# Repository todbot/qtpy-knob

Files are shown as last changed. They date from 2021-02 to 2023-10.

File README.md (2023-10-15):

# QTPy-Knob

QT Py USB Media Knob using rotary encoder &amp; neopixel ring

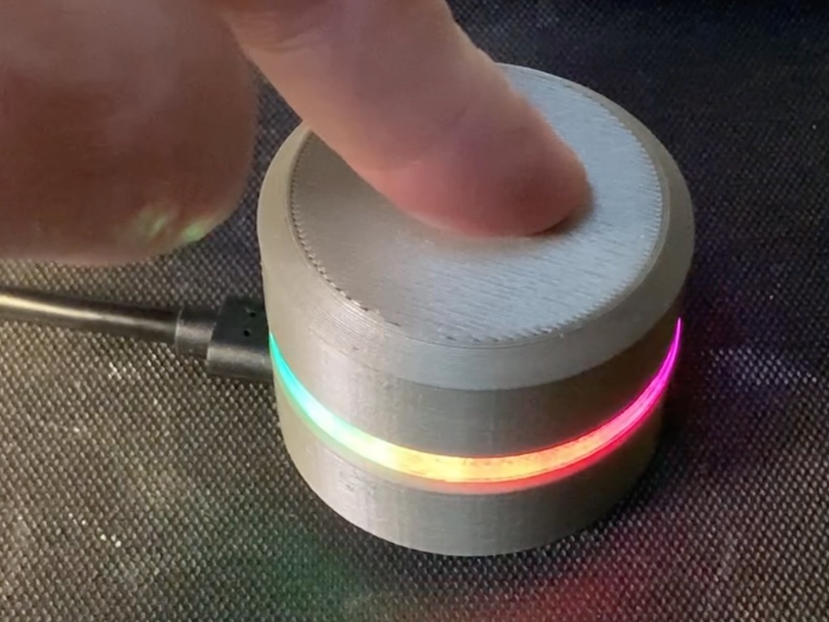
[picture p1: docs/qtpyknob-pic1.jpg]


The QTPy-Knob features:
- Media knob for volume up/down/mute with "qtpy-knob.py" CircuitPython program
- Stylish design reminiscent of Griffin Powermate
- Recessed USB-C connector to for safety
- No screws needed for assembly
- Only 3 wires needed to solder (none if you want to forgo LED lighting)
- Reprogrammable for any USB macro key action via CircuitPython

A small video about it: https://www.youtube.com/watch?v=pt7JgoSlgOg

This is an attempt to make a minimal and easy-to-build version of similar, previous projects like:
- https://learn.adafruit.com/trinket-usb-volume-knob
- https://learn.adafruit.com/media-dial

## Components

Parts needed:

- Adafruit QT Py (Originally for [QTPy M0](https://www.adafruit.com/product/4600) or [XIAO SAMD21](https://www.seeedstudio.com/Seeeduino-XIAO-Arduino-Microcontroller-SAMD21-Cortex-M0+-p-4426.html), but [QTPy RP2040](https://www.adafruit.com/product/4900) does work via a `fakerotaryio` hack)
- Adafruit Neopixel Ring (https://www.adafruit.com/product/1463 or equiv)
- Rotary encoder (PEC11-4120F-S0018 or equiv. The 3D printed case expects encoder w/ 20mm shaft & 7mm threaded barrel, see [here for mods if using a 15mm encoder](https://github.com/todbot/qtpy-knob/issues/2))
- 3D printed enclosure (see "cad" folder)

## Software

For some of the scripts and for some QT Py variants,
there are [prebuilt UF2 firmware images in Releases](https://github.com/todbot/qtpy-knob/releases).

Otherwise, software installation consists of:
- Install CircuitPython on the QT Py
- Install required CircuitPython libraries to QT Py
- Copy qtpy_knob.py to QT Py

The CircuitPython installation step is described here: https://learn.adafruit.com/welcome-to-circuitpython/installing-circuitpython

The last two steps can be accomplished with the below

```
git clone https://github.com/todbot/qtpy-knob
cd qtpy-knob
pip3 install circup
circup install -r requirements.txt
cp qtpy_knob.py /Volumes/CIRCUITPY/code.py
```

**RP2040 NOTE:** And if you have a QTPy RP2040, be sure to copy the "fakerotaryio.py" file to CIRCUITPY as well.

### Variations

There are a few variations of the code provided:
- [`qtpy_knob.py`](./qtpy_knob.py)  -- volume up / down and mute
- [`qtpy_knob_scroller.py`](./qtpy_knob_scroller.py) -- performs vertical & horizontal scrolling
- [`qtpy_knob_midi_cc.py`](./qtpy_knob_midi_cc.py) -- sends MIDI CC instead of keyboard/mouse
- [`qtpy_knob_simple.py`](./qtpy_knob_simple.py) -- no neopixel stuff, just encoder and USB vol up/down sending

## Assembly

Steps:

1. Plug rotary encoder to bottom of QT Py. If your encoder has metal on the bottom,
add a bit of tape (Kapton, Scotch, electrical) in between the QT Py and the encoder.  If your encoder has mounting tabs, cut them off.  Solder the five pins.

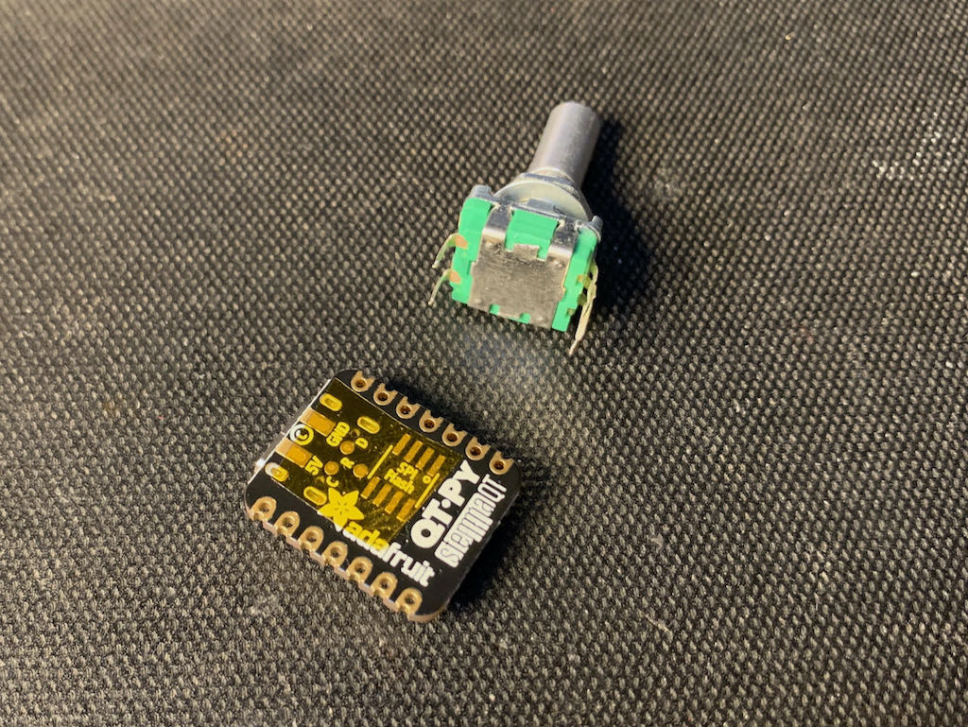
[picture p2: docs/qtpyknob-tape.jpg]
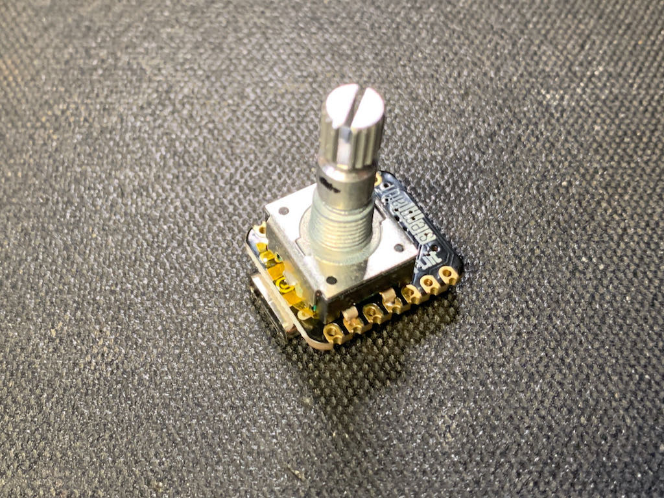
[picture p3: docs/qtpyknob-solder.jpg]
  

2. Print out the enclosure on your 3d printer. Standard 0.2mm at 20% infill is fine.  The STL files are:

- `qtpyknob-base.stl` -- Base that houses the QT Py & rotary encoder
- `qtpyknob-basecap.stl` -- Cap that goes on the bottom of the base
- `qtpyknob-knob.stl` -- Knob that you turn
- `qtpyknob-diffuser.stl` -- Light diffuser that goes between base & knob, should be printed with translucent or clear plastic. Or you can leave it out. Or you can approxiate it with a disk cut out clear plastic like a CD case

Use the rotary encoder's washer & screw to hold QTPy+encoder assembly

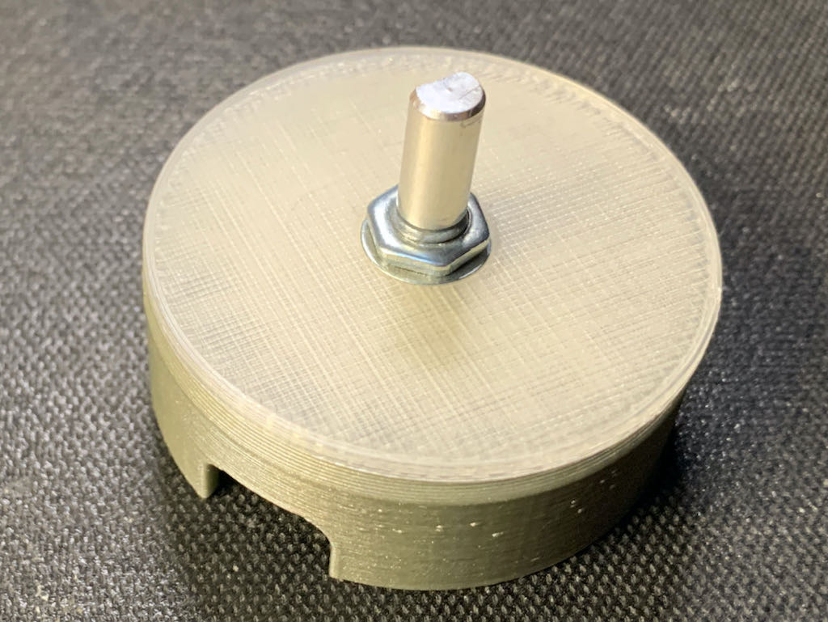
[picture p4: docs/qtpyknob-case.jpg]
  

3. Solder three wires to the Neopixel ring, insert the ring into the enclosure and solder the wires to the 3V, Gnd, and MI pins of the QT Py.  Use a bit of hot glue to secure the Neopixel ring if it doesn't snap in.

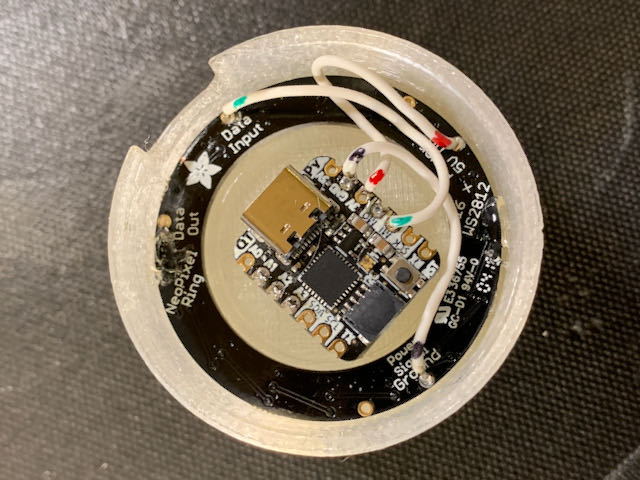
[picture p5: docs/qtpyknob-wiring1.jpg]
  

4. Snap the bottom cap on and the knob top on and you're done with physical assembly!

  

### Wiring diagram

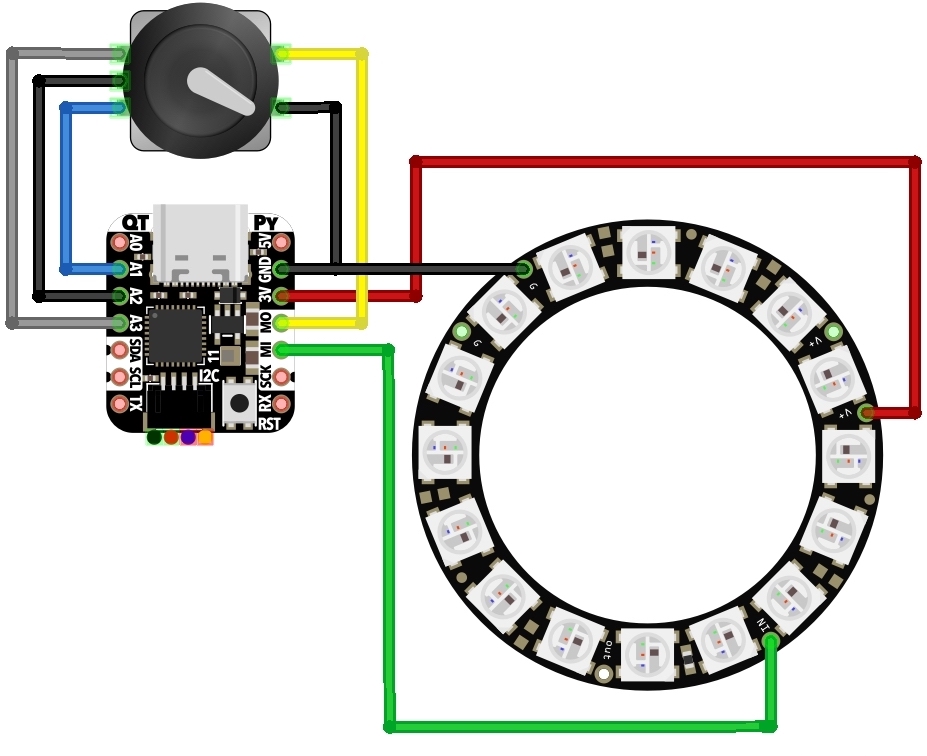
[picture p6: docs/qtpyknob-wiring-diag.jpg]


### Assembly animation



## Useful links

Resources that helped me out on this:

- https://learn.adafruit.com/media-dial
- https://learn.adafruit.com/make-it-a-keyboard/circuitpython
- https://github.com/adafruit/Adafruit_CircuitPython_HID/tree/master/examples
- https://circuitpython.readthedocs.io/projects/hid/en/latest/api.html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
- https://learn.adafruit.com/trinket-usb-volume-knob

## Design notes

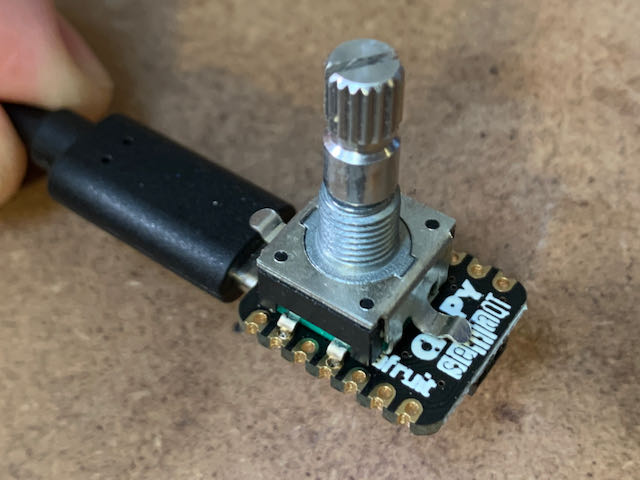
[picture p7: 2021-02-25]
docs/qtpyknob-encoder-mount.jpg

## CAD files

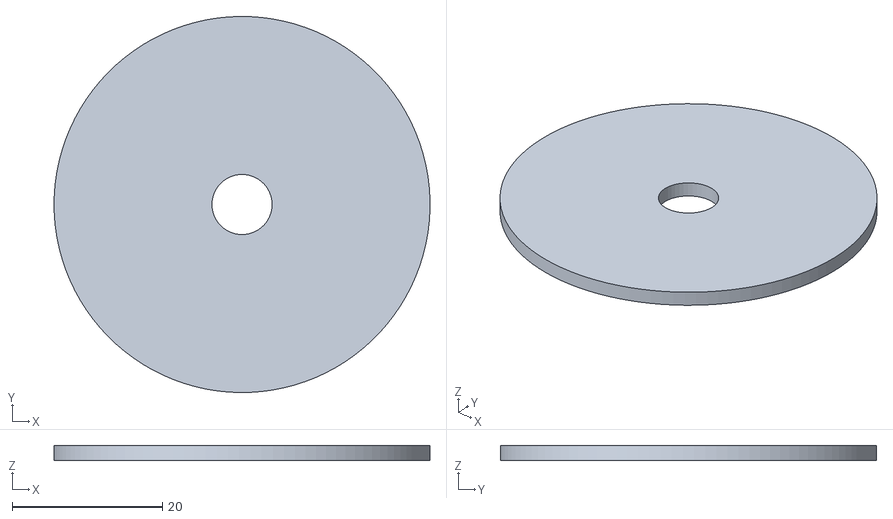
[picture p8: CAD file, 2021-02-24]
cad/qtpyknob-diffuser.stl
50.0 x 50.0 x 2.00

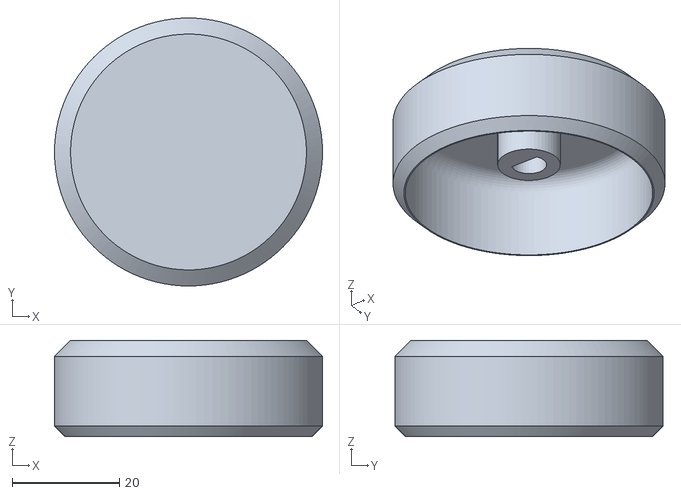
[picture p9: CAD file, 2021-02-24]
cad/qtpyknob-knob.stl
50.0 x 50.0 x 18.0

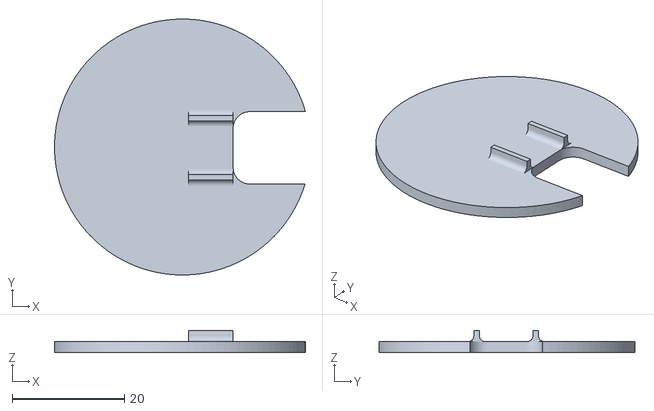
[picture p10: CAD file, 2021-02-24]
cad/qtpyknob-basecap.stl
44.8 x 45.7 x 4.00

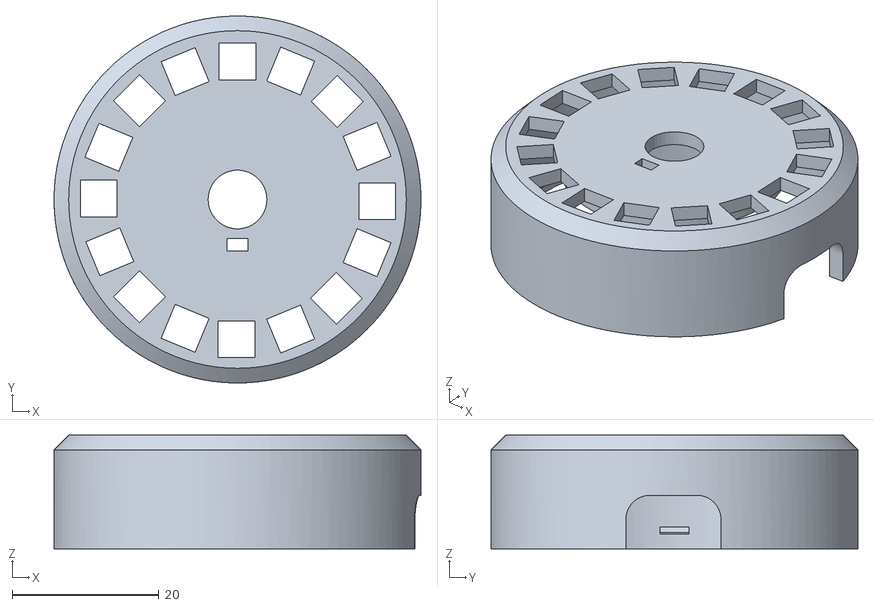
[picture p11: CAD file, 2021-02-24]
cad/qtpyknob-base.stl
50.0 x 50.0 x 15.5

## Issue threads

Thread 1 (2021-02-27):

Renaming to avoid "-" and use "_".

dglaude, 2021-02-27:
Thank you for this piece of code and great idea.

Just a suggestion to avoid "-" into python file name and user "_" instead.

This permit to never rename the original file from the project and have a code.py like this:
```
import qtpy_knob_simple
#import qtpy_knob_scroller
#import qtpy_knob
```

PS: I have both QT-Py and Seeduino XIAO in the same form factor... my QT-Py is more precious because it has reset button, Stemma-QT pin, RGB. So I wanted to rename the pin for XIAO use... but there is no need, your code works out of the box on the same physical pin with the same code. Only the through hole seems smaller on the XIAO so it does not fit perfectly flush. Did I mention it does also kind of work without soldering!!!

todbot, 2021-02-27:
Hi David! Thanks, but I wasn't intending any of these .py to be used straight but to be copied over as the `code.py`.  How can it work if you're importing them?  Wouldn't the `while True:` mess it up?

todbot, 2021-02-27:
Oh and yes we are fortunate that the CircuitPython config for the XIAO contains both the pin names it has on the bottom as well as the pin names of the QT Py in its 'board' object.  I was pleasantly surprised too! (because I have a pile of XIAOs and have been wanting to use them up, so in the video, both of the enclosed units are actually XIAO boards :-)

dglaude, 2021-02-27:
The import from code.py works fine.
That is what Info all the time, my code.py is just a program selector or choose the test I want to run.

To answer your question, you just never return from the import.

One may also want to import directly from REPL and have no code.py and no main.py.

I see no good reason to use character that block that.

dglaude, 2021-02-27:
The import from code.py works fine.
That is what Info all the time, my code.py is just a program selector or choose the test I want to run.

To answer your question, you just never return from the import.

One may also want to import directly from REPL and have no code.py and no main.py.

I see no good reason to use character that block that.

todbot, 2021-02-27:
Interesting!  Okay, sounds like a good change to make then.  Do you have a link to your program selector? Sounds pretty useful.

dglaude, 2021-02-27:
My program selector is to put a # in front of all but the code I want to test. :-)

But there was a menu system I once saw for board with a screen, there is a feature to select what will be the "code.py" or "main.py" at next boot. This is useful if you have multiple games on a PyGamer.

What I made is a magtag boot selector: https://gist.github.com/dglaude/4bf8d0a13c9c8ca8b05d6c0e9176bd20
Later that was turned into a guide with a GUI: https://learn.adafruit.com/adafruit-magtag-project-selector

Closed 2021-02-27.

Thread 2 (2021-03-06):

minor issues around encoder fit

scruss, 2021-03-06:
Noticed a couple of things when using the specified Bourns PEC11-4215F-S24 encoder:

1. The diffuser ring is too thick for the lock nut to fasten. It's 2 mm thick, and there's exactly 2 mm of thread left on the encoder.
2. The D-shaft cutout in the top is too deep to allow the encoder shaft switch to trigger.

Otherwise, it's a fantastic project and very easy to make. Yes, I used a Seeeduino XIAO, too

## Workarounds

I made the central part of the diffuser thinner so the lock nut would fasten. Excuse the OpenSCAD, it's all I know:

    bbox = [ 49.988811, 49.994404, 2.000000 ];
    minima = [ -25.000000, -24.997202, 2.700000 ];

    difference() {
        translate([-bbox.x/2, -bbox.y/2, 0])translate(-minima)import("qtpyknob-diffuser.stl");
        translate([0,0,0.8])cylinder(d=bbox.x/2, h=bbox.z);
    }

For the D-shaft cutout, a blob of Blu Tack of just the right size mostly fixes the issue.

todbot, 2021-03-06:
Doh! So many encoder options to pick from.
I see now that the ones I'm using are PEC11-4120F-S0018 equivalent (i.e. 20mm shaft with 7mm threaded barrel and you've got a 15mm shaft with a 5mm threaded barrel.  I think your option is more common. I have a bunch of extra encoders from some modular synth projects. :)

I'll add a note about expected encoder in the README and keep this issue open for others to easily see it.  Thanks!  I totally forgot to specify the encoder parameters.

bdgraham, 2022-08-09:
Obviously due to the negligence of the user (me) not reading the readme fully, the rotary encoder I have won't fit into the d-shaft cutout as the shaft I have is the regular kind.  Do you have a qtyknob-knob.stl available with the regular size shaft cut out?  All measurements are spot on otherwise.  If not, totally fine as I can extract that portion in blender if needed.  Awesome work, I've really wanted to make a functional volume knob for a while!  I also created an svg for the diffuser as I am going to be using a laser cutter for that part.  If you would like me add that file to your repo, please let me know!

For reference, this is the rotary encoder I am using - https://www.amazon.com/dp/B08728K3YB?psc=1&ref=ppx_yo2ov_dt_b_product_details

todbot, 2022-08-09:
Hi @bdgraham
I can provide solid models from the included Fusion360 file if that'd work better in Blender for you. But no, I've not made either a knurled-shaft or a slotted-shaft version of the knob cap.

And yeah if you have a diffuser SVG you'd like to share, submit a PR, I'd love to add it!

bdgraham, 2022-08-09:
@todbot A solid model would be great, thanks!  I'll get that PR submitted in the meantime.

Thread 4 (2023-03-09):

2023 - circuit python 8.0.3 - sequential pins rotaryio?

xgpt, 2023-03-09:
le.
main.py output:
Traceback (most recent call last):
  File "main.py", line 30, in <module>
RuntimeError: Pins must be sequential GPIO pins

Code done running.

Press any key to enter the REPL. Use CTRL-D to reload.

todbot, 2023-03-09:
Looks like you're using a QT Py RP2040.  This project was created before those existed, and only works with the original QT Py M0.

xgpt, 2023-03-11:
Oh interesting, I wasn't sure why that might be happening!

adalovebass, 2023-10-14:
Sorry to bump, but @xgpt , did you find a workaround? I may just cut my pins and bridge with wires to sequential pins... :/

And @todbot , would you be willing to update the "components" section to call out the M0? I didn't realize there were different versions of the QT Pi and I didn't order directly from the link. Thank you both!

todbot, 2023-10-14:
@adalovebass  Yep I'll do that.  I'll also see about a solution for the RP2040.

adalovebass, 2023-10-14:
That's awesome! Technically I'm on a xiao-rp2040, but all the .pins are in the same spot as the QT Pi, I just have less memory (and need to cherry-pick my python modules).

xgpt, 2023-10-14:
> Sorry to bump, but @xgpt , did you find a workaround? I may just cut my pins and bridge with wires to sequential pins... :/
>
> And @todbot , would you be willing to update the "components" section to call out the M0? I didn't realize there were different versions of the QT Pi and I didn't order directly from the link. Thank you both!

I'm out of town and away from my desk, but I can look at the prototype I ended up with and send you a schematic of the pinout when I get back from my trip!

todbot, 2023-10-14:
Ooo, @xgpt, I'd love to see that!

I also just updated `qtpy_knob.py` to use a new `fakerotaryio` module I created and put in this repo that will let you do rotaryio stuff on non-sequential pins.  It's not as good as real `rotaryio` but should work for this application.

adalovebass, 2023-10-14:
Omgosh thank you both! I am kind of new, so figured I could remove the rotary encoder lead from D1 and wire it to D4 instead, so the pins used were D3 and D4:
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

But apparently in the GPIO sense D3 and D4 are not actually sequential. I found this thread that mentions `help(microcontroller.pin)`, the output of which indicates that on the _Adafruit QT Py proper_, D3 and D5 are actually GPIO sequential (link and screenshot):
https://github.com/adafruit/circuitpython/issues/5334
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

This seems like a potential location for the rotary encoder, if you can do a fake ground on D10 for the push-button.

Unfortunately, between my D3/D4 attempt, and moving the bridging wire from D4 to D5, my board doesn't seem to be recognized by Windows any more (have tried unsoldering everything, and boot mode, to no avail) (and it was a comparatively clean, cool, and successful desoldering and resoldering, so not sure what's happening with that). 😄 Regardless, I haven't been able to run `help(microcontroller.pin)`, nor test the concept.

In the meantime, thanks for the update to use fakerotaryio, I'll check it out when my new board shows up 😭 (I bought 2 so I can put header pins in one and prototype on a breadboard this time!)

todbot, 2023-10-14:
@adalovebass looks like you're running Adafruit QTPy firmware on that XIAO.  They're pretty different internally, I'd recommend installing [XIAO RP2040 CircuitPython](https://circuitpython.org/board/seeeduino_xiao_rp2040/)

adalovebass, 2023-10-15:
Thanks for lookin' out for me! To clarify, I am running the firmware you linked, the output of the `help(microcontroller.pin)` command was not my own, but from a QTPy user in the linked thread, which supports my hypothesis about pins D3 and D5 being sequential. I'll run it on my own board to make sure, or to find a similar pattern, when I get my replacement board :)

todbot, 2023-10-15:
@adalovebass ahh got it! In the XIAO pinout diagram, the gray labels are the chip GPIO pin numbers and it's those that must be sequential. (e.g. D3 & D5 are GPIO P29 & P7) It's confusing and I've been bit by it multiple times too, with both rotary encoders and [I2S audio](https://github.com/adafruit/circuitpython/issues/8058). And it doesn't help that `rotaryio`'s error message isn't clear on this even with the fix (most users I think don't get the difference between silkscreen pin names and GPIO pin names)

adalovebass, 2023-10-15:
Oh gosh! :D Yeah, the "micropython pin numbers" needing to be sequential was certainly not clear! But it does seem like D10 and D8 would be sequential, as their micropython pin numbers are P3 and P2. I figure I can get D9 to do the "fake ground." Then I see your code uses MISO and MOSI (shared with D8 and D9) for the Neopixel Ring and Rotary Encoder's button, but I am pretty sure those can use any digital pin based on some other example I've seen. I'll let you know if I find a solution that works with the standard rotaryio library. I really appreciate you sharing your expertise, and hope this is all still relevant to this ticket :)

adalovebass, 2023-10-16:
So I did find a solution that works:

```
		     +--------+
	LED	Din--|D0	5V|--LED 5v
		     |D1   	 G|--LED G
		     |D2	3V|
		   +-|D3   D10|-+
		   | |D4	D9|-)-+
		 +-)-|D5	D8|-)-)-+
		 | | |D6	D7| | | |
		 | | +--------+ | | |
         | | XIAO RP2040| | |
         | |            | | |
		 | | Rotary Enc | | |
		 | |  +------+  | | |
		 | +--|SW1  A|--+ | |
		 |    |     G|----+ |
		 +----|SW2  B|------+
		      +------+
```

Code changes:
* Button to D3
* LED data pin to D0
* Fakeground D5 and D9

Since I have limited storage space I manually added these to /lib directory:
* adafruit_hid/
* adafruit_led_animation/
* digitalio.mpy
* neopixel.mpy
* rotaryio.mpy

Zip file with libraries here: https://github.com/adafruit/Adafruit_CircuitPython_Bundle/releases/tag/20231013

Specifically I used the 8.x bundle from there (direct link here: https://github.com/adafruit/Adafruit_CircuitPython_Bundle/releases/download/20231013/adafruit-circuitpython-bundle-8.x-mpy-20231013.zip )

Of course the .stl's won't necessarily fit, as the USB port and encoder knob are now on opposite sides of the board. BUT, it's possible to run this on the XIAO RP2040, using the elegant direct-mounting-of-encoder-to-board solution!

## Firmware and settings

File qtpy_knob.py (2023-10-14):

# qtpy_knob.py -- Mount a rotary encoder directly to an Adafruit QT Py,
#                 add some neopixels and get a USB media knob
# https://github.com/todbot/qtpy-knob
# 2021-2023 @todbot / Tod Kurt

# pylint: disable=invalid-name
#
"""
qtpy_knob

"""
import os
import time
import board
from digitalio import DigitalInOut, Direction, Pull
import neopixel
import usb_hid
from rainbowio import colorwheel
from adafruit_hid.consumer_control import ConsumerControl
from adafruit_hid.consumer_control_code import ConsumerControlCode

if os.uname().machine.find("rp2040") > 0:  # RP2040
    from fakerotaryio import IncrementalEncoder
else:
    from rotaryio import IncrementalEncoder


# config: number of seconds to keep LED ring on, 0 == keep on forever
ring_on_time = 0

# config: print out qtpy_knob state to REPL
debug = False

# 16 position neopixel ring
ring = neopixel.NeoPixel(board.MISO, 16, brightness=0.2, auto_write=False)

# button of rotary encoder
button = DigitalInOut(board.MOSI)
button.pull = Pull.UP

# Use pin A2 as a fake ground for the rotary encoder
fakegnd = DigitalInOut(board.A2)
fakegnd.direction = Direction.OUTPUT
fakegnd.value = False

encoder = IncrementalEncoder( board.A3, board.A1 )

cc = ConsumerControl(usb_hid.devices)

last_encoder_val = encoder.position
ring_pos = 0
rainbow_pos = 0
last_time = 0
ring_on = True

def color_int_to_tuple(val):
    """Convert a 24-bit color int to a 3-int tuple"""
    return (val >> 16 & 0xff, val >> 8 & 0xff, val >> 0 & 0xff)

print("hello from qtpy-knob!")

while True:
    encoder_pos = encoder.position
    encoder_diff = last_encoder_val - encoder_pos  # encoder clicks since last read
    last_encoder_val = encoder_pos
    ring_pos = (ring_pos + encoder_diff) % len(ring)    # position on LED ring
    fun_color = colorwheel( (20 + encoder_pos*4) % 255 )     # fun hue change based on pos
    fun_color = color_int_to_tuple(fun_color)  # convert to tuple for down below

    # LED ring goes off after a time of no activity
    if encoder_diff !=0 or button.value is False:
        last_time = time.monotonic()

    ring_on = (ring_on_time==0 or time.monotonic() - last_time < ring_on_time)

    if button.value is False:                   # button pressed
        cc.send(ConsumerControlCode.MUTE)       # toggle mute
        while not button.value:                 # wait for release
            time.sleep(0.05)
            # spin the rainbow while held
            for i in range(len(ring)):   # pylint: disable=consider-using-enumerate
                pixel_index = (i*256 // len(ring)) + rainbow_pos
                ring[i] = colorwheel( pixel_index & 255 )
                ring.show()
                rainbow_pos = (rainbow_pos + 1) % 256
    else:
        if encoder_diff > 0:
            for i in range(encoder_diff):
                cc.send(ConsumerControlCode.VOLUME_DECREMENT)
                time.sleep(0.01)
        elif encoder_diff < 0:
            for i in range(-encoder_diff):
                cc.send(ConsumerControlCode.VOLUME_INCREMENT)
                time.sleep(0.01)

        if ring_on:
            ring.fill( [int(i/2) for i in fun_color] ) # make it 1/2 dimmer
            ring[ring_pos] = (255,255,255)  # 'pointer' of where knob is
            ring[(ring_pos-1)%len(ring)] = (37,37,37) # and some surrounds for pointer
            ring[(ring_pos+1)%len(ring)] = (37,37,37)
        else:  # fade out LED ring if past ring_on_time
            ring[:] = [[max(i-10,0) for i in l] for l in ring]
        ring.show()

        if debug:
            print(ring_on,encoder_pos,encoder_diff,button.value,ring_pos)
        time.sleep(0.01)

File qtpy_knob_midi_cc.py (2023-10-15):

"""
`qtpy_knob_midi_cc.py` -- Mount a rotary encoder directly to an Adafruit QT Py,
                          add some neopixels and get a USB scrolling knob
                          Turning knob scrolls vertically,
                          pressing & turning scrolls horizontally

 NOTE:  This is different from other qtpy_knob programs in that you will need to
        delete the 'adafruit_hid' library and install the 'adafruit_midi' library

 https://github.com/todbot/qtpy-knob/
 2021-2023 @todbot / Tod Kurt
"""
# pylint: disable=invalid-name, consider-using-enumerate

import os
import time
import board
from digitalio import DigitalInOut, Pull
import neopixel
import usb_midi
import adafruit_midi
from adafruit_midi.control_change import ControlChange

if os.uname().machine.find("rp2040") > 0:  # RP2040
    from fakerotaryio import IncrementalEncoder
else:
    from rotaryio import IncrementalEncoder

cc_num = 44        # what control change number to send on
cc_mult_fine = 4   # how much to multiply raw value by
cc_mult_coarse = 8 # how much to multiply raw value by when button pressed
cc_val = 0         # starting (and current) value of the control change value

# 16 position neopixel ring
ring = neopixel.NeoPixel(board.MISO, 16, brightness=0.2, auto_write=False)

# button of rotary encoder
button = DigitalInOut(board.MOSI)
button.switch_to_input(pull=Pull.UP)

# Use pin A2 as a fake ground for the rotary encoder
fakegnd = DigitalInOut(board.A2)
fakegnd.switch_to_output( value=False )

encoder = IncrementalEncoder( board.A3, board.A1 )

midi = adafruit_midi.MIDI(midi_out=usb_midi.ports[1], out_channel=0)

print("hello from qtpy_knob_midi_cc!")

# standard colorwheel
def colorwheel(pos):
    """Emulate rainbowio.colorwheel, sorta"""
    if pos < 0 or pos > 255:
        (r,g,b) = (0,0,0)
    elif pos < 85:
        (r,g,b) = (int(pos * 3), int(255 - pos * 3), 0)
    elif pos < 170:
        pos -= 85
        (r,g,b) = (int(255 - pos * 3), 0, int(pos * 3))
    else:
        pos -= 170
        (r,g,b) = (0, int(pos * 3), int(255 - pos * 3))
    return (r, g, b)


last_encoder_val = encoder.position
ring_pos = 0
rainbow_pos = 0

cc_mult = cc_mult_fine

while True:
    diff = last_encoder_val - encoder.position  # encoder clicks since last read
    last_encoder_val = encoder.position
    ring_pos = (ring_pos + diff) % len(ring)    # position on LED ring
    hue = colorwheel( encoder.position*4 % 255 )     # fun hue change based on pos

    if not button.value:                        # button pressed
        cc_mult = cc_mult_coarse
        for i in range(len(ring)):          # spin the rainbow while held
            pixel_index = (i*256 // len(ring)) + rainbow_pos
            ring[i] = colorwheel( pixel_index & 255 )
            ring.show()
            rainbow_pos = (rainbow_pos + 1) % 256
    else:
        cc_mult = cc_mult_fine

        ring.fill( [int(i/4) for i in hue] ) # make it 1/4 dimmer
        ring[ring_pos] = (255,255,255)
        ring[(ring_pos-1)%len(ring)] = (67,67,67)
        ring[(ring_pos+1)%len(ring)] = (67,67,67)
        ring.show()

    if diff != 0:  # only send if there's a change
        print("sending")
        cc_val = cc_val - (diff*cc_mult)
        cc_val = max(min(127,cc_val), 0)  # clamp to 0-127
        #cc_val = 0 if n < 0 else 127 if n > 127 else cc_val  # clamp to 0-127

        midi.send([ControlChange(44, cc_val)])

    print(encoder.position,diff,button.value,ring_pos,cc_val)
    time.sleep(0.05)

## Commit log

2021-02-24 cleanup more
    [qtpyknob-base.stl, qtpyknob-basecap.stl, qtpyknob-diffuser.stl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]
2021-02-25 added wiring diag
2021-02-25 fix bad bottom of wiring diag
2021-02-25 added fritzing source
    [qtpyknob.fzz]
2021-02-25 added v27 of Fusion 360 CAD archive
2021-02-25 added encoder mount jpg
2021-02-25 added encoder wiring jpg
2021-02-26 3d print instructions
2021-02-27 rename py files to work with import, fix issue #1
    [qtpy_knob.py, qtpy_knob_scroller.py, qtpy_knob_simple.py]
2021-03-03 added LED ring fade idle fade out, disabled by default
2021-03-06 update readme about encoder options
2023-10-14 update qtpy_knob for RP2040 by creating a fakerotaryio using keypad, issue #4
    [fakerotaryio.py, qtpy_knob.py]
